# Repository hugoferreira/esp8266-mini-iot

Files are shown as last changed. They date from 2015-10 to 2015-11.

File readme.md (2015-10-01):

ESP8266 07/12 breakout with one Integrated Voltage Regulator (SPX3819M5-L-3-3) for 3v3 (500mA) and LEDs for Power, RX, TX and Charging.
It has a solder jump to connect GPIO16 with RST in order to enable deep sleep.
It also has an integrated LiPo charger (MCP73831), and a Mini-USB port for charging and direct programming through an integrated FTL232RL.

This is a **work in progress** so use at your own risk.

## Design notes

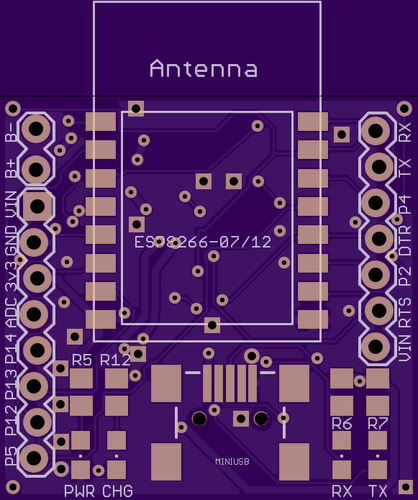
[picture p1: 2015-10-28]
img/top.png

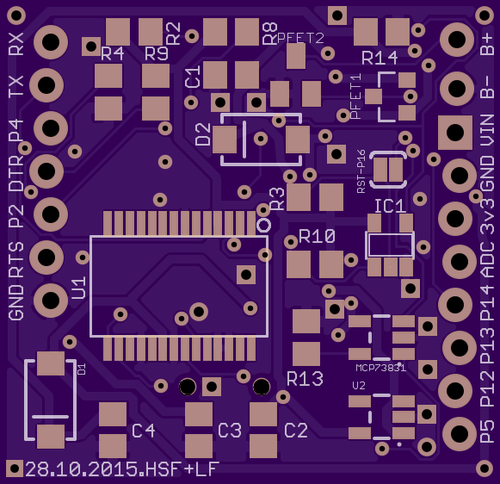
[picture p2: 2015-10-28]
img/bottom.png

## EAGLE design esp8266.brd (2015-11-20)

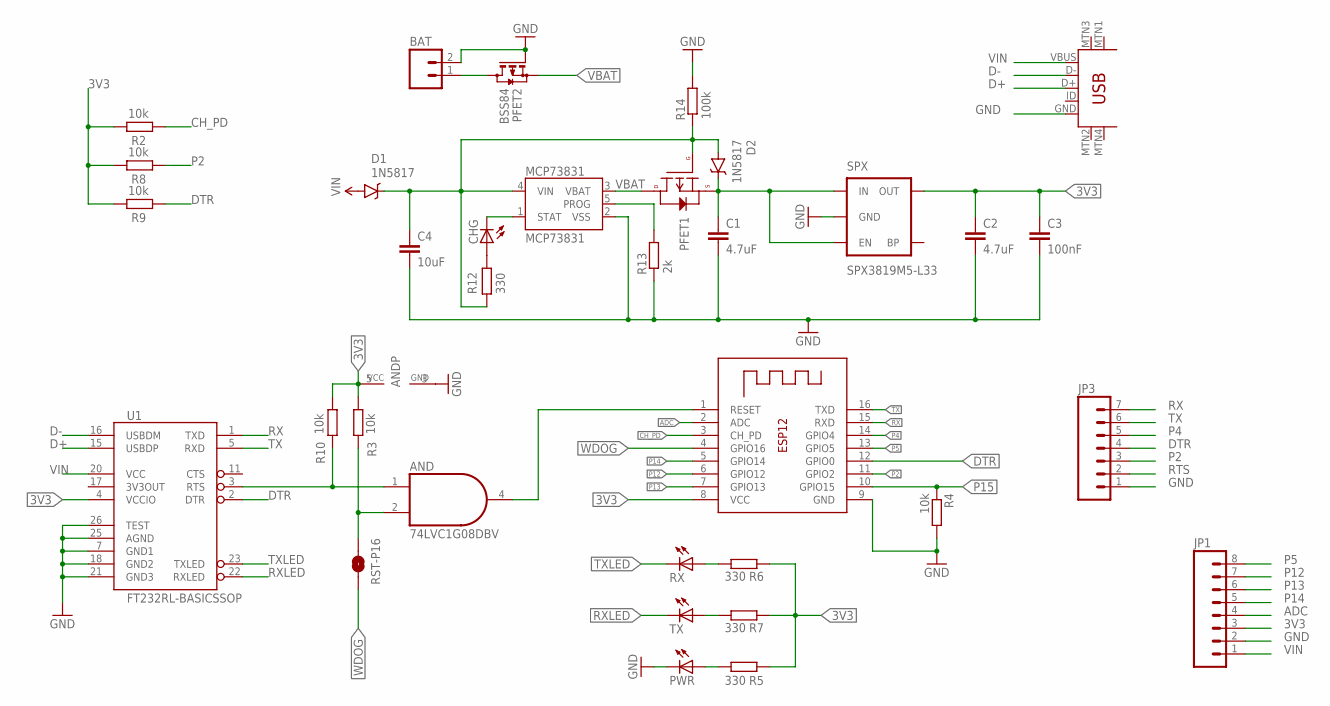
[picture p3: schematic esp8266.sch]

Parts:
AND: 74LVC1G08DBV; SOT23-5
BAT: M02LOCK; 1X02_LOCK
C1, C2: 4.7uF; C0805
C3: 100nF; C0805
C4: 10uF; C0805
CHG: LEDCHIPLED_0805; CHIPLED_0805
D1, D2: 1N5817; SMA-DIODE
ESP8266-07/12: ESP-12
JP1: M08LOCK; 1X08_LOCK
JP3: M07LOCK; 1X07_LOCK
MCP73831: MCP73831; SOT23-5
MINIUSB: USB-MINIB-5PIN; USB-MINIB
PFET1: P-CHANNEL-MOSFET; SOT23-3
PFET2: BSS84; SOT23
PWR: LEDCHIPLED_0805; CHIPLED_0805
R2, R3, R4, R8, R9, R10: 10k; R0805
R5, R6, R7, R12: 330; R0805
R13: 2k; R0805
R14: 100k; R0805
RST-P16: SOLDERJUMPERNO; SJ_2S-NO
RX: LEDCHIPLED_0805; CHIPLED_0805
SPX: SPX3819M5-L33; SOT23-5
TX: LEDCHIPLED_0805; CHIPLED_0805
U1: FT232RL-BASICSSOP; SSOP28DB

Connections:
3V3: AND.5 (VCC), C2.1, C3.1, ESP8266-07/12.8 (VCC), JP1.3, R2.1, R3.2, R5.2, R6.2, R7.2, R8.1, R9.1, R10.2, SPX.5 (OUT), U1.4 (VCCIO)
ADC: ESP8266-07/12.2 (ADC), JP1.4
CH_PD: ESP8266-07/12.3 (CH_PD), R2.2
D+: MINIUSB.D+, U1.15 (USBDP)
D-: MINIUSB.D-, U1.16 (USBDM)
DTR: ESP8266-07/12.12 (GPIO0), JP3.4, R9.2, U1.2 (DTR)
FTDI_RTS: AND.1 (I0), R10.1, U1.3 (RTS)
GND: AND.3 (GND), BAT.2, C1.2, C2.2, C3.2, C4.2, ESP8266-07/12.9 (GND), JP1.2, JP3.1, MCP73831.2 (VSS), MINIUSB.GND, PFET2.1 (G), PWR.C, R4.2, R13.1, R14.2, SPX.2 (GND), U1.7 (GND1), U1.18 (GND2), U1.21 (GND3), U1.25 (AGND), U1.26 (TEST)
unnamed: PWR.A, R5.1
unnamed: C4.1, D1.C, D2.A, MCP73831.4 (VIN), PFET1.1 (G), R12.1, R14.1
unnamed: CHG.A, R12.2
unnamed: AND.2 (I1), R3.1, RST-P16.1
unnamed: BAT.1, PFET2.3 (D)
unnamed: R6.1, RX.A
unnamed: R7.1, TX.A
unnamed: CHG.C, MCP73831.1 (STAT)
unnamed: MCP73831.5 (PROG), R13.2
P2: ESP8266-07/12.11 (GPIO2), JP3.3, R8.2
P4: ESP8266-07/12.14 (GPIO4), JP3.5
P5: ESP8266-07/12.13 (GPIO5), JP1.8
P12: ESP8266-07/12.6 (GPIO12), JP1.7
P13: ESP8266-07/12.7 (GPIO13), JP1.6
P14: ESP8266-07/12.5 (GPIO14), JP1.5
P15: ESP8266-07/12.10 (GPIO15), R4.1
RTS: AND.4 (O), ESP8266-07/12.1 (RESET), JP3.2
RX: ESP8266-07/12.15 (RXD), JP3.7, U1.1 (TXD)
RXLED: TX.C, U1.22 (RXLED)
TX: ESP8266-07/12.16 (TXD), JP3.6, U1.5 (RXD)
TXLED: RX.C, U1.23 (TXLED)
VBAT: MCP73831.3 (VBAT), PFET1.3 (D), PFET2.2 (S)
VIN: D1.A, JP1.1, MINIUSB.VBUS, U1.20 (VCC)
VRIN: C1.1, D2.C, PFET1.2 (S), SPX.1 (IN), SPX.3 (EN)
WDOG: ESP8266-07/12.4 (GPIO16), RST-P16.2

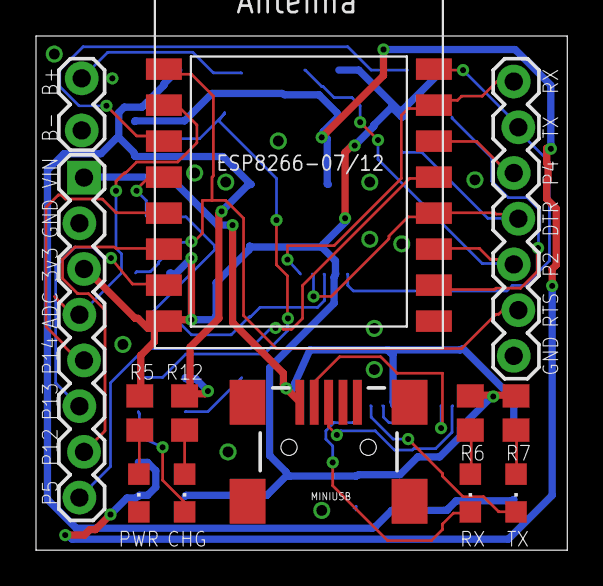
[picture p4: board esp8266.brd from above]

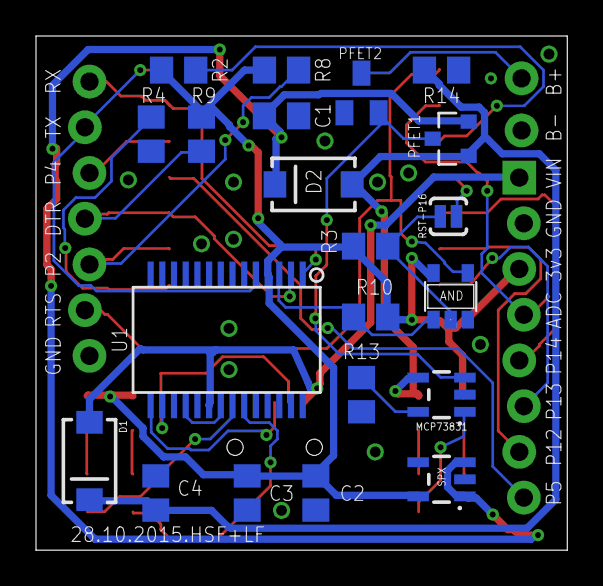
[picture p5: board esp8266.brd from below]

Board: 2 copper layers, 29.5 x 28.6 mm, 34 parts (21 on the bottom side), 33 nets.

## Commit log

2015-08-02 Initial commit.
    [esp8266.brd, esp8266.sch]
2015-08-02 Added rendered boards
2015-08-02 Some board updates
    [esp8266.brd]
2015-09-29 Minor fixes and improvements.
    Watchdog with pull ups and a AND Gate;
    Diode after VIN for satefy reasons;
    Additional VIN pin on the other side of the board for completeness;
    Switched order of pins 13 and 12;
    Small border test holes for VIN and GND.
    [esp8266.brd, esp8266.sch]
2015-09-29 Move signature label to prevent overlap with existing via
    [esp8266.brd]
2015-09-30 Improve labeling position
    [esp8266.brd]
2015-09-30 Add RX and TX probes at the corners and minor style fixes
    [esp8266.brd]
2015-10-02 Added OSHPark design rules Fixed half a dozen design rules violations (overlapping and clearance).
    [esp8266.brd]
2015-10-02 Optimised the layout: deleted several redundant wires and at least one via.
    [esp8266.brd]
2015-10-02 Even less wires and 3 unnecessary vias.
    [esp8266.brd]
2015-10-02 I kinda need to stop doing this…
    [esp8266.brd]
2015-10-23 Improve the clarity of the FDTI orientation
    This was accomplish by moving the via a to a higher position so that it doesn't interfere with the markings.
    [esp8266.brd]
2015-10-27 Remove unnecessary components
    RTS had a capacitor that is not required per FTDI spec and is also not needed for this
    circuit. There were also 2 10k pull-ups on the RTS.
    [esp8266.brd, esp8266.sch]
2015-10-27 Update board images
2015-10-28 Change the second VIN to ground
    It's more useful that way.
    [esp8266.brd, esp8266.sch]
2015-10-30 New routing
    [esp8266.brd, esp8266.sch]
2015-11-01 Finished routing
    [esp8266.brd]
2015-11-02 Fix clearence issues
    [esp8266.brd]
2015-11-02 More clearance adjustments and labeling improvements
    [esp8266.brd, esp8266.sch]

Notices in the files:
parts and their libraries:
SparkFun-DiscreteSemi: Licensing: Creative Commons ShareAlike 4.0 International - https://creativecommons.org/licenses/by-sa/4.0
